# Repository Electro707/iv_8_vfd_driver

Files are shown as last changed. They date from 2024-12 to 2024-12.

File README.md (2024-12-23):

# Dual IV-8 VFD Display Drivers

This project is to drive two IV-8 displays

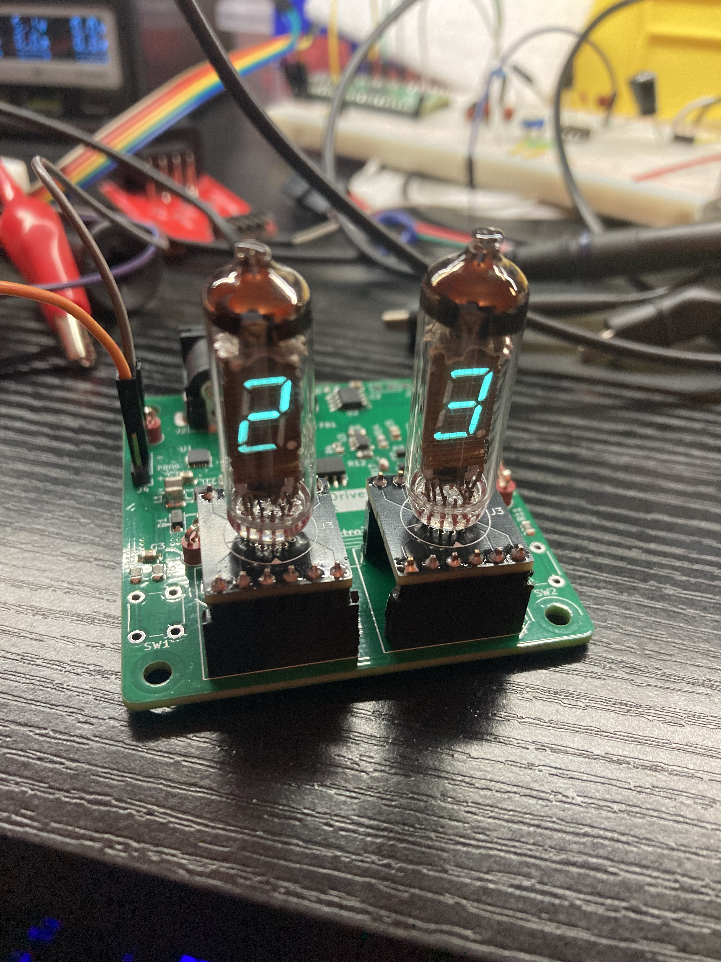
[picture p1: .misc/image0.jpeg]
Image of board, 2024-12-21


# History

This project started because I scored two IV-8 VFD Displays off a flea market, and thus I needed something to drive them

# Project Structure
- CAD: FreeCAD source files for the enclosure (WIP)
- PCB_Driver: KiCAD files for the driver board
- PCB_IV-8: KiCAD files for the IV-8 mounting board
- PCB_IV-8_Test: KiCAD files for a test board equivalent to above, used before using a real display in case the circuit is borked
- Sim_Osci: KiCAD files for a simulation of the oscillating circuit, taken from an EEVBlog forum
- Firmware_count: A simple firmware that counts the VFDs up from 0 to 99
- Firmware_main1: The primary firmware, this one also implements UART communication with a host

# Driver Board Issue, Rev 1
There were some erratas that proped out during testing of Rev 1 of the driver board. The following hardware bug fixes must be made for the board to be usable
- For the filament drive circuit, R17 needs to be shorted, and add two series 25ohm resistor (by cutting traces) of `FIL_A` and `FIL_B`
- Add a series 100kohm resistor between the Q1-Q3 and the outputs of Q6 to the gate of the PFET
    - Turns out there was a maximum Source-to-Gate limit of +-20v, which this circuit clearly exceeds when driving the FETs. With the 100k resistor, when driving the segment Vgs is at -5.83v

# License
This project is licensed under GPLv3. See [LICENSE.md](LICENSE.md) for details.

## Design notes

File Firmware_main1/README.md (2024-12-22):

# Firmware

## Cmake Targets
- `<No Arguments>`: Builds the firmware
- `flash`: Flashes the firmware using jtag2updi, which can be uploaded unto an Arduino board and connected to this board with a 4.7k series resistor
    - See the [jtag2udpi](https://github.com/ElTangas/jtag2updi) project for more details on programming and connections
    - You may have to change the jtag2updi port in CmakeLists.txt

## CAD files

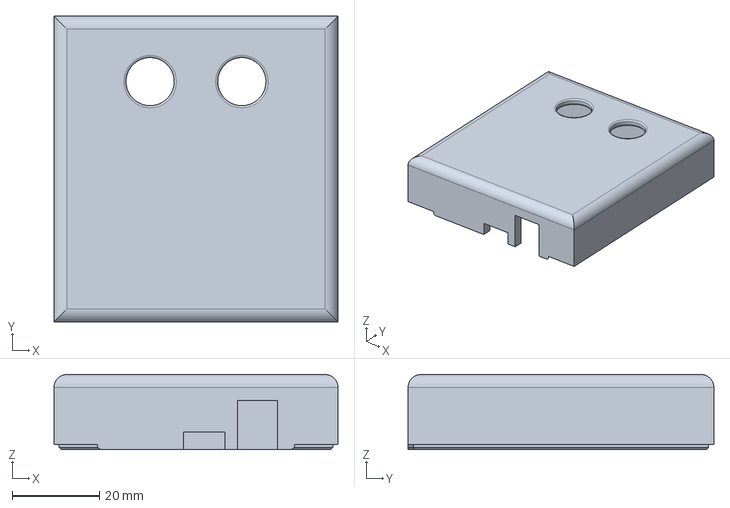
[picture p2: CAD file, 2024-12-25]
CAD/Top.FCStd
65.0 x 70.0 x 17.2 mm

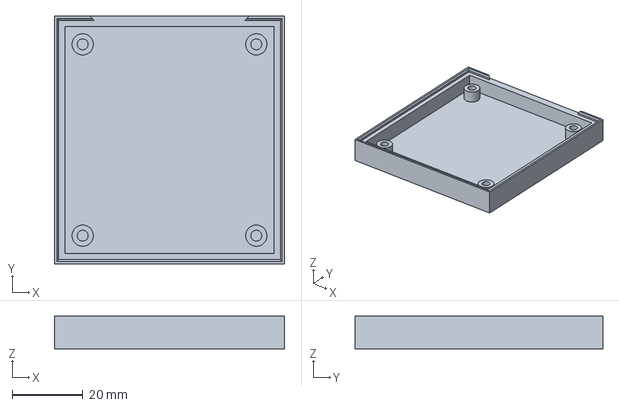
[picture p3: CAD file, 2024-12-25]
CAD/Bottom.FCStd
65.0 x 70.0 x 9.20 mm

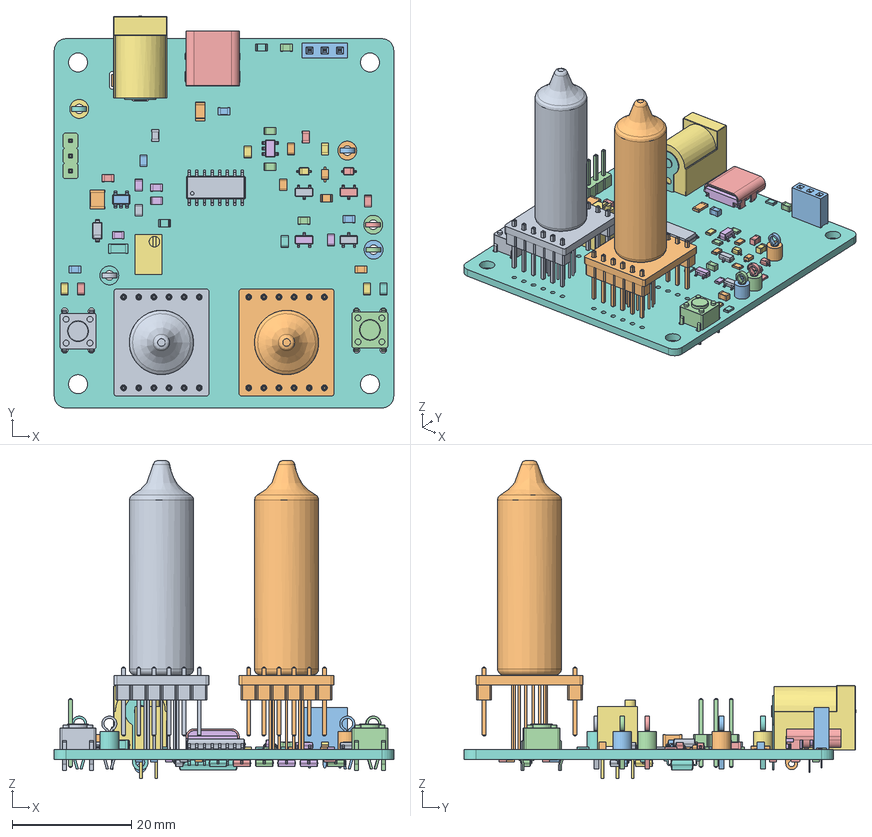
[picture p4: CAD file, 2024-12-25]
CAD/PCB.FCStd
57.0 x 65.8 x 53.4 mm
SOT_23
R_0805_2012Metric
R_0805_2012Metric002
C_0805_2012Metric
SOT_024
R_0805_2012Metric004
L_0805_2012Metric
C_1206_3216Metric
SW_PUSH_6mm
C_0805_2012Metric002
TestPoint_Keystone_5005_5009_Compact_cp
TestPoint_Keystone_5005_5009_Compact_cp001
C_0805_2012Metric004
R_0805_2012Metric006
TestPoint_Keystone_5005_5009_Compact_cp003
TestPoint_Keystone_5005_5009_Compact_cp004
SOIC_16_39x99mm_P127mm
R_0805_2012Metric008
C_0805_2012Metric006
R_0805_2012Metric010
R_0805_2012Metric012
C_0805_2012Metric008
R_0805_2012Metric014
R_0805_2012Metric016
C_0805_2012Metric010
L_1210_3225Metric
L_0805_2012Metric002
C_0805_2012Metric012
USB_C_Receptacle_GCT_USB4085
USB_C_Receptacle_GCT_USB4086
USB_C_Receptacle_GCT_USB4087
USB_C_Receptacle_GCT_USB4088
USB_C_Receptacle_GCT_USB4089
USB_C_Receptacle_GCT_USB4090
USB_C_Receptacle_GCT_USB4091
USB_C_Receptacle_GCT_USB4092
USB_C_Receptacle_GCT_USB4093
USB_C_Receptacle_GCT_USB4094
USB_C_Receptacle_GCT_USB4095
USB_C_Receptacle_GCT_USB4096
USB_C_Receptacle_GCT_USB4097
USB_C_Receptacle_GCT_USB4098
USB_C_Receptacle_GCT_USB4099
USB_C_Receptacle_GCT_USB4100
USB_C_Receptacle_GCT_USB4101
USB_C_Receptacle_GCT_USB4102
USB_C_Receptacle_GCT_USB4103
USB_C_Receptacle_GCT_USB4104
USB_C_Receptacle_GCT_USB4105
USB_C_Receptacle_GCT_USB4106
USB_C_Receptacle_GCT_USB4107
USB_C_Receptacle_GCT_USB4108
USB_C_Receptacle_GCT_USB4109
USB_C_Receptacle_GCT_USB4110
USB_C_Receptacle_GCT_USB4111
USB_C_Receptacle_GCT_USB4112
USB_C_Receptacle_GCT_USB4113
USB_C_Receptacle_GCT_USB4114
USB_C_Receptacle_GCT_USB4115
USB_C_Receptacle_GCT_USB4116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

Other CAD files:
CAD/Assy.FCStd

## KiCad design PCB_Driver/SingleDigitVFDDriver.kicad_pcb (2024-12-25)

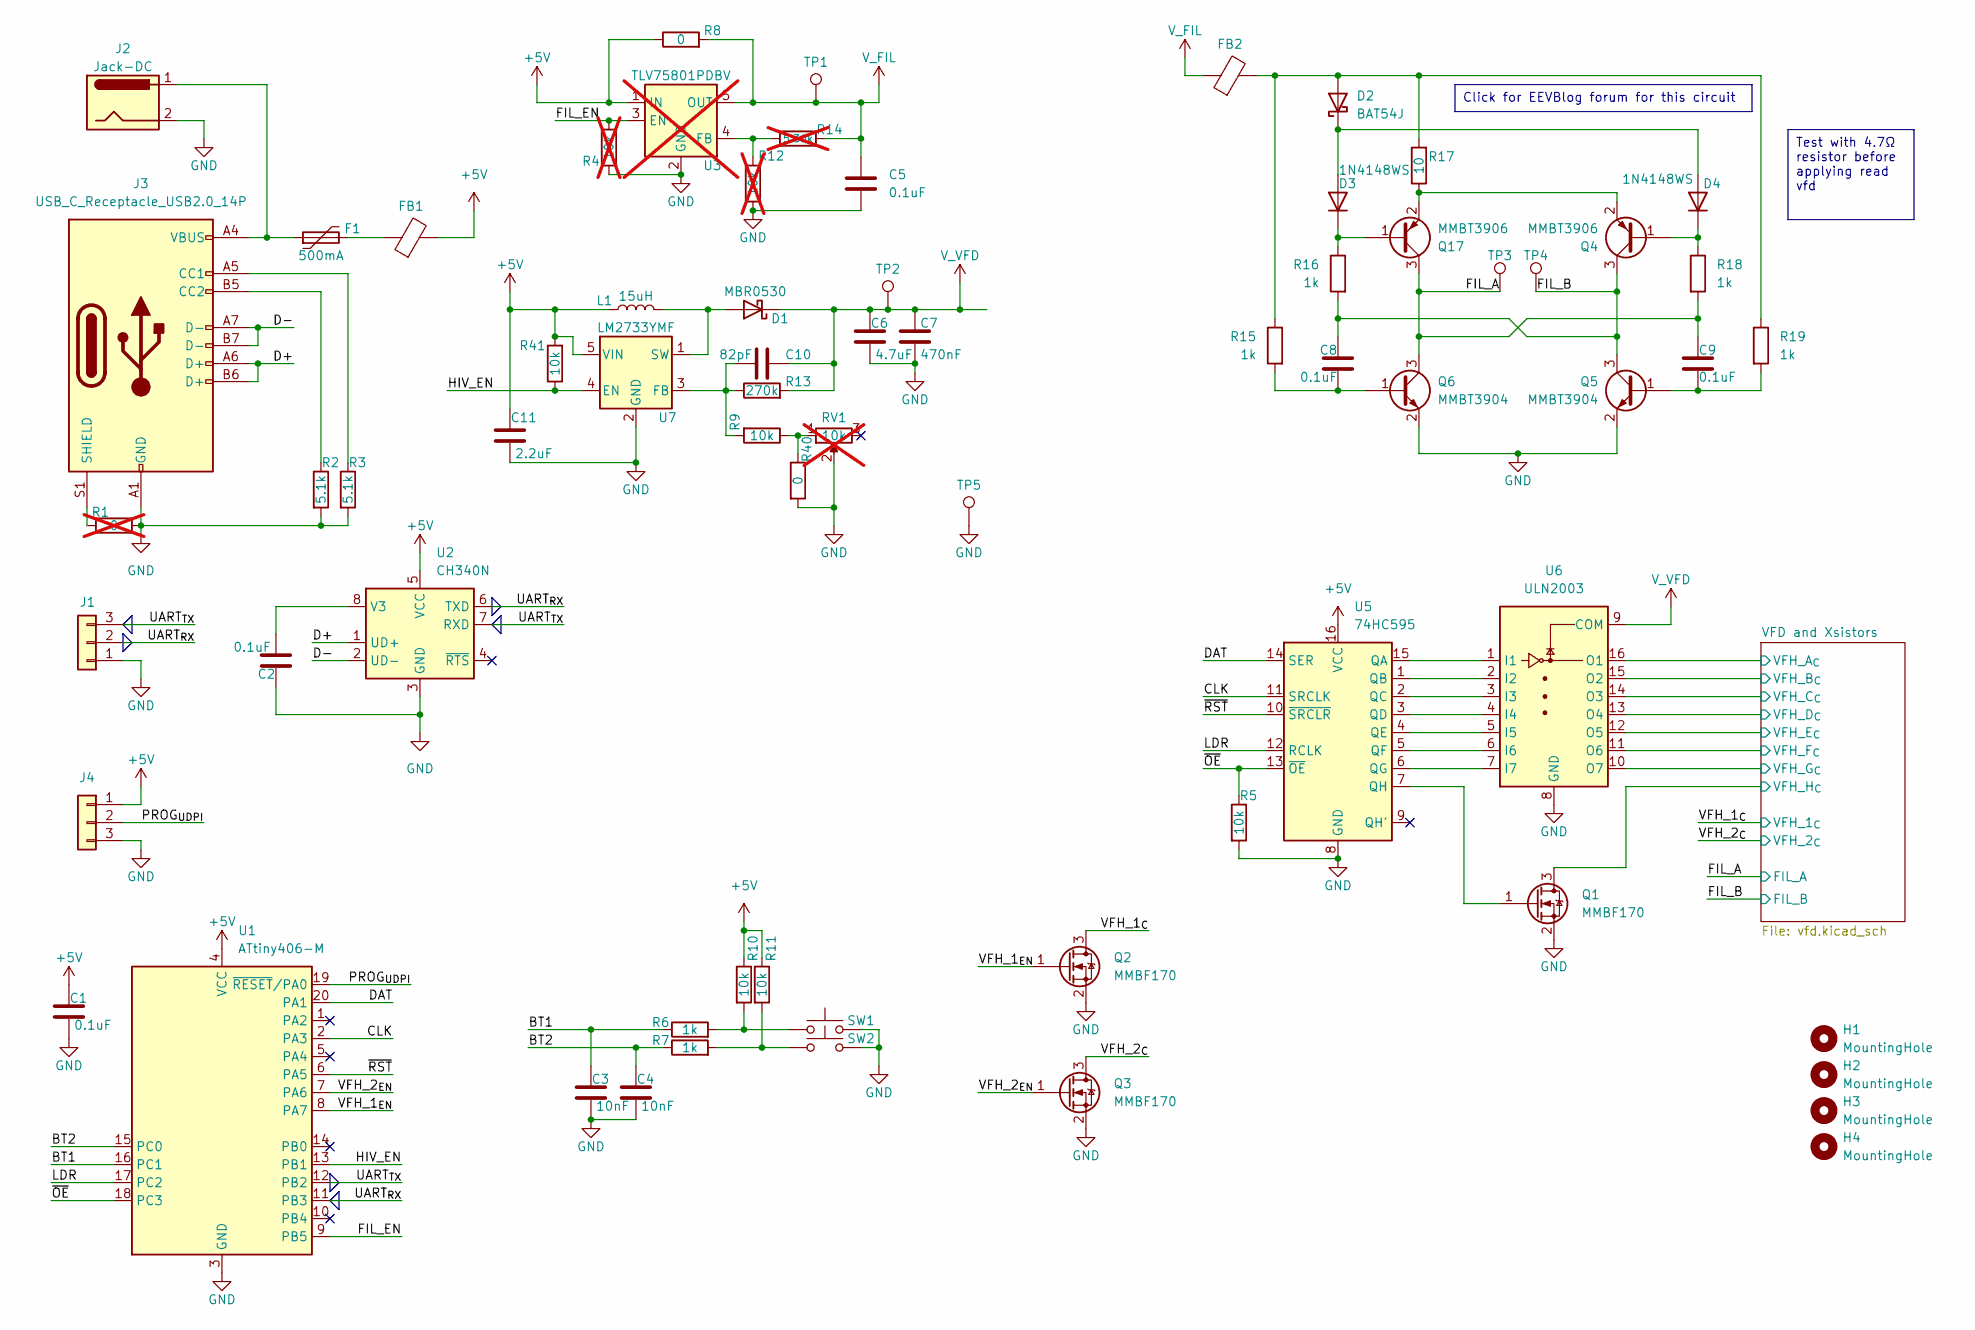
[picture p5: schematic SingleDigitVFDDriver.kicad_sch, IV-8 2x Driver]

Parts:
C1, C2, C5, C8, C9: 0.1uF; C_0805_2012Metric
C3, C4: 10nF; C_0805_2012Metric
C6: 4.7uF; C_1206_3216Metric
C7: 470nF; C_0805_2012Metric
C10: 82pF; C_0805_2012Metric
C11: 2.2uF; C_0805_2012Metric
D1: MBR0530; D_SOD-123
D2: BAT54J; D_SOD-323F
D3, D4: 1N4148WS; D_SOD-323
F1: 500mA; Fuse_1206_3216Metric
FB1, FB2: FerriteBead; L_0805_2012Metric
H1, H2, H3, H4: MountingHole; MountingHole_3.2mm_M3_DIN965
J1: Conn_01x03; PinSocket_1x03_P2.54mm_Vertical
J2: Jack-DC; BarrelJack_Horizontal
J3: USB_C_Receptacle_USB2.0_14P; USB_C_Receptacle_GCT_USB4085
J4: Conn_01x03; PinHeader_1x03_P2.54mm_Vertical
L1: 15uH; L_1210_3225Metric
Q1, Q2, Q3: MMBF170; SOT-23
Q4, Q17: MMBT3906; SOT-23
Q5, Q6: MMBT3904; SOT-23
R1: 0; R_0805_2012Metric; not fitted
R2, R3: 5.1k; R_0805_2012Metric
R4, R12: 10k; R_0805_2012Metric; not fitted
R5, R9, R10, R11, R41: 10k; R_0805_2012Metric
R6, R7, R15, R16, R18, R19: 1k; R_0805_2012Metric
R8, R40: 0; R_0805_2012Metric
R13: 270k; R_0805_2012Metric
R14: 5.36k; R_0805_2012Metric; not fitted
R17: 10; R_0805_2012Metric
RV1: 10k; Potentiometer_Bourns_3266W_Vertical; not fitted
SW1, SW2: SW_Push; SW_PUSH_6mm
TP1, TP2, TP3, TP4, TP5: TestPoint; TestPoint_Keystone_5005-5009_Compact
U1: ATtiny406-M; VQFN-20-1EP_3x3mm_P0.4mm_EP1.7x1.7mm
U2: CH340N; SOP-8_3.9x4.9mm_P1.27mm
U3: TLV75801PDBV; SOT-23-5; not fitted
U5: 74HC595; SOIC-16_3.9x9.9mm_P1.27mm
U6: ULN2003; SOIC-16_3.9x9.9mm_P1.27mm
U7: LM2733YMF; SOT-23-5

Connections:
+5V: C1.1, C11.1, FB1.2, J4.1, L1.1, R8.1, R10.1, R11.1, R41.2, U1.4 (VCC), U2.5 (VCC), U3.1 (IN), U5.16 (VCC), U7.5 (VIN)
/BT1: C3.1, R6.1, U1.16 (PC1)
/BT2: C4.1, R7.1, U1.15 (PC0)
/CLK: U1.2 (PA3), U5.11 (SRCLK)
/D+: J3.A6 (D+), J3.B6 (D+), U2.1 (UD+)
/D-: J3.A7 (D-), J3.B7 (D-), U2.2 (UD-)
/DAT: U1.20 (PA1), U5.14 (SER)
/FIL_A: C9.1, Q6.3 (C), Q17.3 (C), R18.2, TP3.1; also elsewhere on the board
/FIL_B: C8.1, Q4.3 (C), Q5.3 (C), R16.2, TP4.1; also elsewhere on the board
/FIL_EN: R4.2, U1.9 (PB5), U3.3 (EN)
/HIV_EN: R41.1, U1.13 (PB1), U7.4 (EN)
/LDR: U1.17 (PC2), U5.12 (RCLK)
/PROG_{UDPI}: J4.2, U1.19 (~RESET/PA0)
/UART_{RX}: J1.2, U1.11 (PB3), U2.6 (TXD)
/UART_{TX}: J1.3, U1.12 (PB2), U2.7 (RXD)
/VFD and Xsistors/VFH_A_{C}: U6.16 (O1); also elsewhere on the board
/VFD and Xsistors/VFH_B_{C}: U6.15 (O2); also elsewhere on the board
/VFD and Xsistors/VFH_C_{C}: U6.14 (O3); also elsewhere on the board
/VFD and Xsistors/VFH_D_{C}: U6.13 (O4); also elsewhere on the board
/VFD and Xsistors/VFH_E_{C}: U6.12 (O5); also elsewhere on the board
/VFD and Xsistors/VFH_F_{C}: U6.11 (O6); also elsewhere on the board
/VFD and Xsistors/VFH_G_{C}: U6.10 (O7); also elsewhere on the board
/VFD and Xsistors/VFH_H_{C}: Q1.3 (D); also elsewhere on the board
/VFH_1_{C}: Q2.3 (D); also elsewhere on the board
/VFH_1_{EN}: Q2.1 (G), U1.8 (PA7)
/VFH_2_{C}: Q3.3 (D); also elsewhere on the board
/VFH_2_{EN}: Q3.1 (G), U1.7 (PA6)
/~OE: R5.1, U1.18 (PC3), U5.13 (~OE)
/~RST: U1.6 (PA5), U5.10 (~SRCLR)
GND: C1.2, C2.1, C3.2, C4.2, C5.2, C6.2, C7.2, C11.2, J1.1, J2.2, J3.A1 (GND), J3.A12 (GND), J3.B1 (GND), J3.B12 (GND), J4.3, Q1.2 (S), Q2.2 (S), Q3.2 (S), Q5.2 (E), Q6.2 (E), R1.2, R2.2, R3.2, R4.1, R5.2, R12.1, R40.2, RV1.2, SW1.2, SW2.2, TP5.1, U1.3 (GND), U1.21 (GND), U2.3 (GND), U3.2 (GND), U5.8 (GND), U6.8 (GND), U7.2 (GND); also elsewhere on the board
unnamed: D1.2 (A), L1.2, U7.1 (SW)
unnamed: D2.2 (A), FB2.2, R15.1, R17.2, R19.1
unnamed: D2.1 (K), D3.2 (A), D4.2 (A)
unnamed: D3.1 (K), Q17.1 (B), R16.1
unnamed: D4.1 (K), Q4.1 (B), R18.1
unnamed: F1.1, J2.1, J3.A4 (VBUS), J3.A9 (VBUS), J3.B4 (VBUS), J3.B9 (VBUS)
unnamed: F1.2, FB1.1
unnamed: J3.A5 (CC1), R3.1
unnamed: J3.B5 (CC2), R2.1
unnamed: J3.S1 (SHIELD), R1.1
unnamed: Q1.1 (G), U5.7 (QH)
unnamed: C9.2, Q5.1 (B), R19.2
unnamed: C8.2, Q6.1 (B), R15.2
unnamed: Q4.2 (E), Q17.2 (E), R17.1
unnamed: R6.2, R10.2, SW1.1
unnamed: R7.2, R11.2, SW2.1
unnamed: R9.1, R40.1, RV1.1
unnamed: C2.2, U2.8 (V3)
unnamed: R12.2, R14.1, U3.4 (FB)
unnamed: U5.15 (QA), U6.1 (I1)
unnamed: U5.1 (QB), U6.2 (I2)
unnamed: U5.2 (QC), U6.3 (I3)
unnamed: U5.3 (QD), U6.4 (I4)
unnamed: U5.4 (QE), U6.5 (I5)
unnamed: U5.5 (QF), U6.6 (I6)
unnamed: U5.6 (QG), U6.7 (I7)
unnamed: C10.1, R9.2, R13.1, U7.3 (FB)
V_FIL: C5.1, FB2.1, R8.2, R14.2, TP1.1, U3.5 (OUT)
V_VFD: C6.1, C7.1, C10.2, D1.1 (K), R13.2, TP2.1, U6.9 (COM); also elsewhere on the board

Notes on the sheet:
Click for EEVBlog forum for this circuit
Test with 4.7Ω resistor before applying read vfd

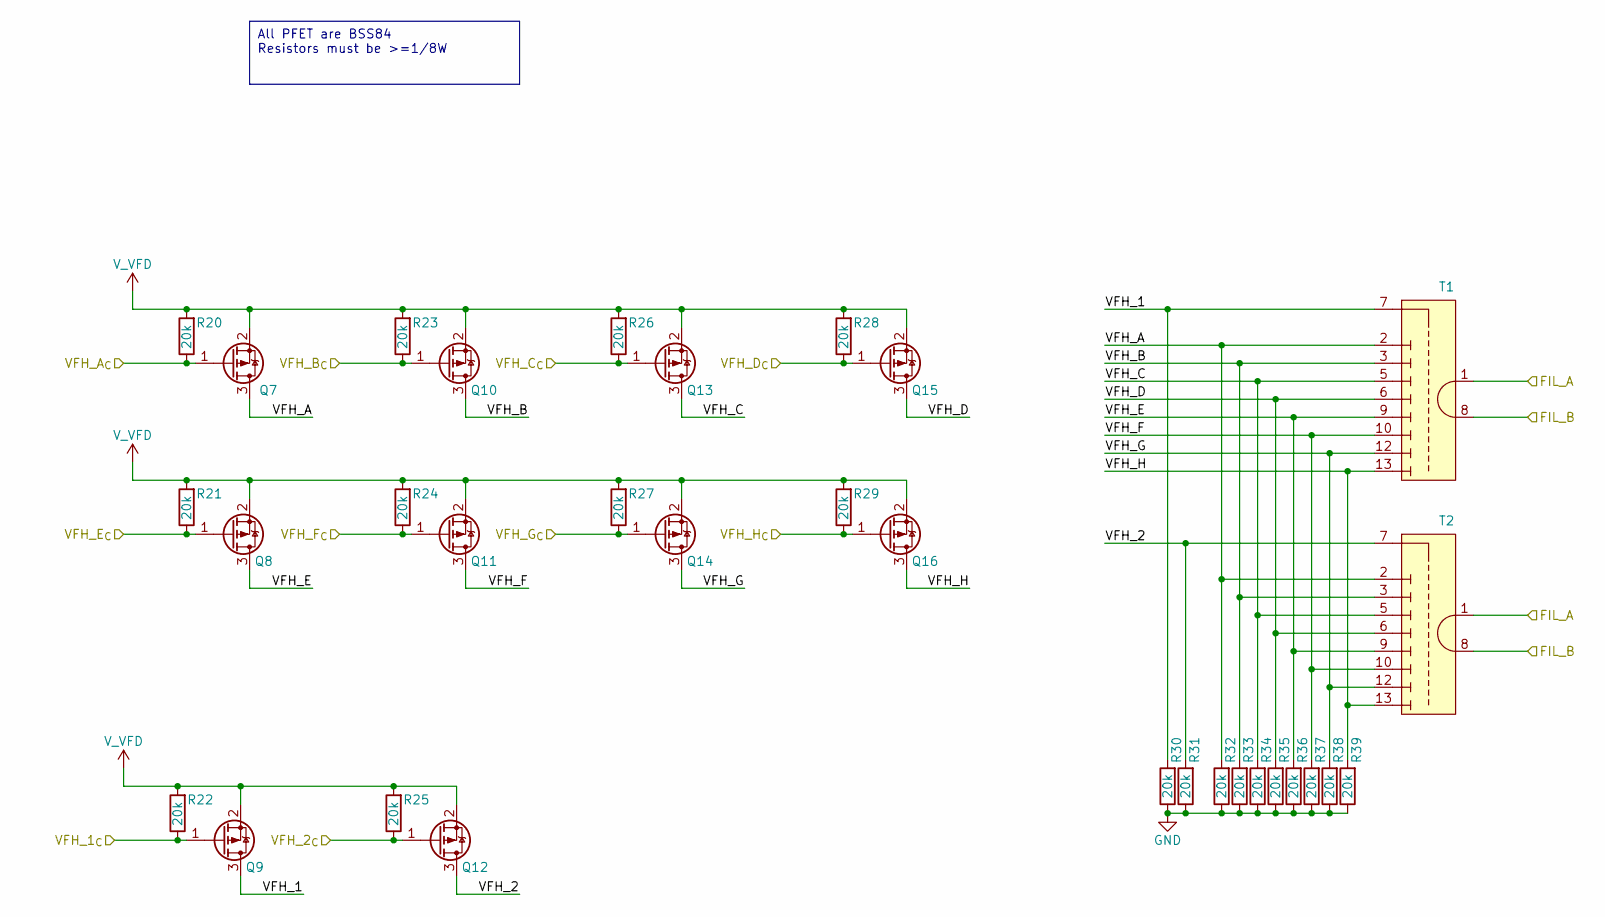
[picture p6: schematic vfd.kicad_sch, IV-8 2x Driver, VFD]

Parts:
Q7, Q8, Q9, Q10, Q11, Q12, Q13, Q14, Q15, Q16: BSS84; SOT-23
R20, R21, R22, R23, R24, R25, R26, R27, R28, R29, R30, R31, R32, R33, R34, R35, R36, R37, R38, R39: 20k; R_0805_2012Metric
T1, T2: IV-8 Adapter

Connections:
/FIL_A: T1.1, T2.1; also elsewhere on the board
/FIL_B: T1.8, T2.8; also elsewhere on the board
/VFD and Xsistors/VFH_1: Q9.3 (D), R30.2, T1.7
/VFD and Xsistors/VFH_2: Q12.3 (D), R31.2, T2.7
/VFD and Xsistors/VFH_A: Q7.3 (D), R32.2, T1.2, T2.2
/VFD and Xsistors/VFH_A_{C}: Q7.1 (G), R20.1; also elsewhere on the board
/VFD and Xsistors/VFH_B: Q10.3 (D), R33.2, T1.3, T2.3
/VFD and Xsistors/VFH_B_{C}: Q10.1 (G), R23.1; also elsewhere on the board
/VFD and Xsistors/VFH_C: Q13.3 (D), R34.2, T1.5, T2.5
/VFD and Xsistors/VFH_C_{C}: Q13.1 (G), R26.1; also elsewhere on the board
/VFD and Xsistors/VFH_D: Q15.3 (D), R35.2, T1.6, T2.6
/VFD and Xsistors/VFH_D_{C}: Q15.1 (G), R28.1; also elsewhere on the board
/VFD and Xsistors/VFH_E: Q8.3 (D), R36.2, T1.9, T2.9
/VFD and Xsistors/VFH_E_{C}: Q8.1 (G), R21.1; also elsewhere on the board
/VFD and Xsistors/VFH_F: Q11.3 (D), R37.2, T1.10, T2.10
/VFD and Xsistors/VFH_F_{C}: Q11.1 (G), R24.1; also elsewhere on the board
/VFD and Xsistors/VFH_G: Q14.3 (D), R38.2, T1.12, T2.12
/VFD and Xsistors/VFH_G_{C}: Q14.1 (G), R27.1; also elsewhere on the board
/VFD and Xsistors/VFH_H: Q16.3 (D), R39.2, T1.13, T2.13
/VFD and Xsistors/VFH_H_{C}: Q16.1 (G), R29.1; also elsewhere on the board
/VFH_1_{C}: Q9.1 (G), R22.1; also elsewhere on the board
/VFH_2_{C}: Q12.1 (G), R25.1; also elsewhere on the board
GND: R30.1, R31.1, R32.1, R33.1, R34.1, R35.1, R36.1, R37.1, R38.1, R39.1; also elsewhere on the board
V_VFD: Q7.2 (S), Q8.2 (S), Q9.2 (S), Q10.2 (S), Q11.2 (S), Q12.2 (S), Q13.2 (S), Q14.2 (S), Q15.2 (S), Q16.2 (S), R20.2, R21.2, R22.2, R23.2, R24.2, R25.2, R26.2, R27.2, R28.2, R29.2; also elsewhere on the board

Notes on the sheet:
All PFET are BSS84 Resistors must be >=1/8W

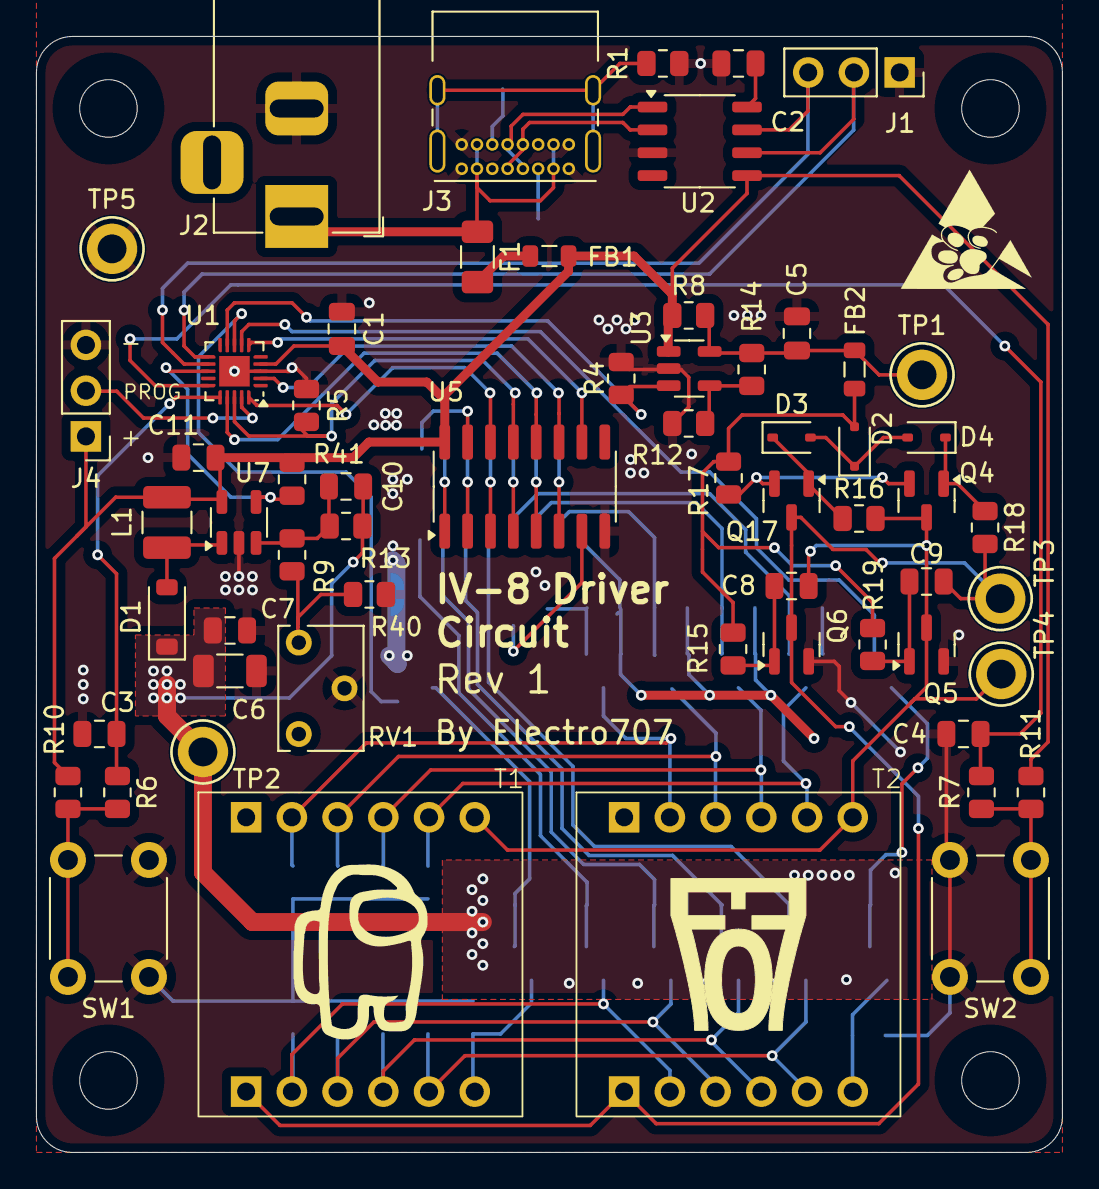
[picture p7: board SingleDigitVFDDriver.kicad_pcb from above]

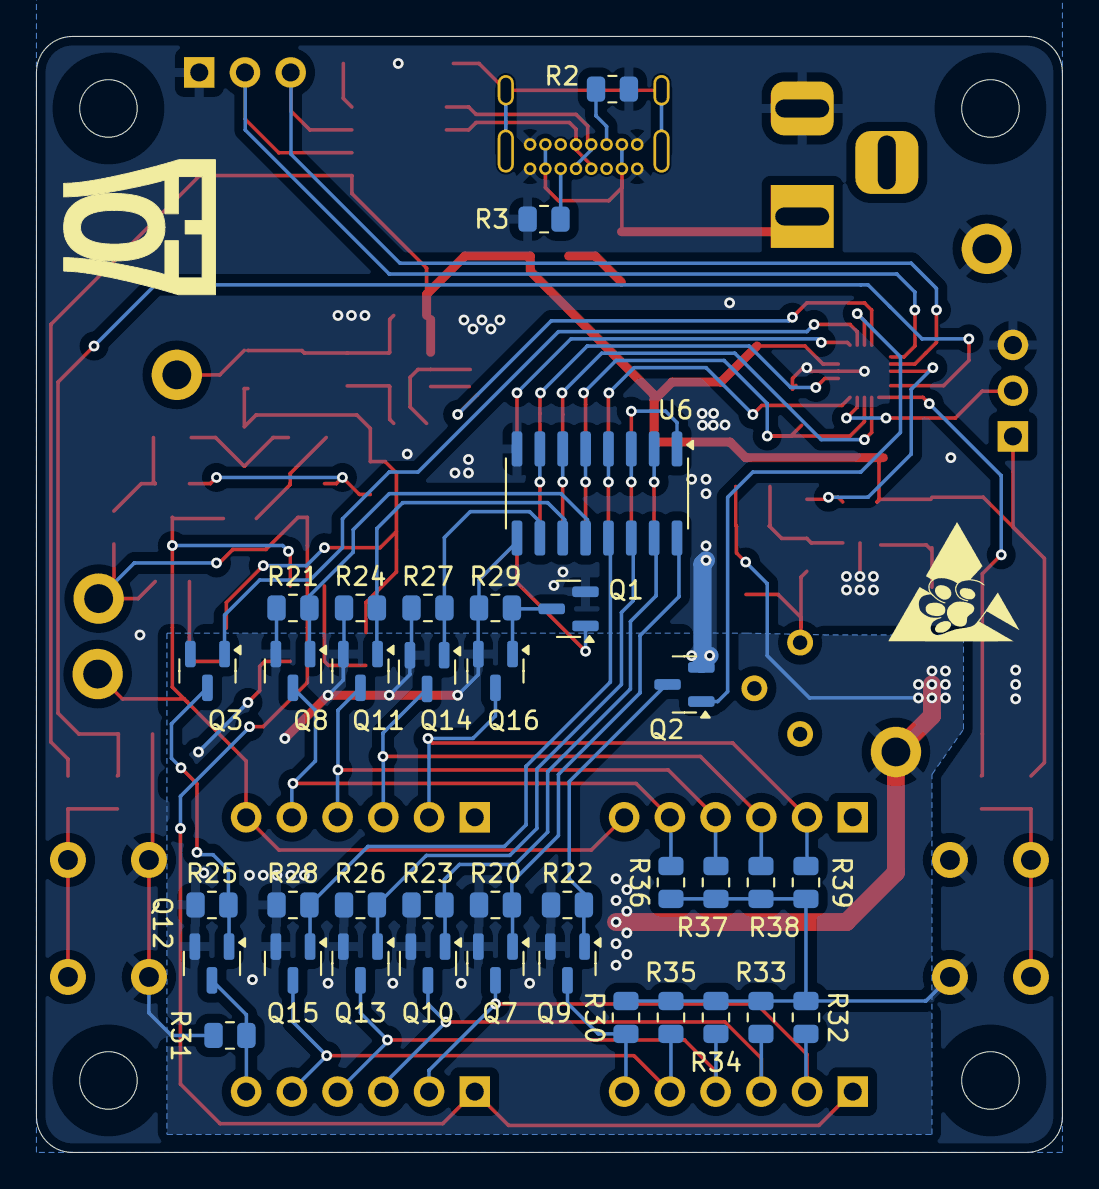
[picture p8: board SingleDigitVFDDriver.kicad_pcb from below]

Board: 2 copper layers, 57.0 x 62.0 mm, 101 parts (36 on the bottom side), 69 nets.

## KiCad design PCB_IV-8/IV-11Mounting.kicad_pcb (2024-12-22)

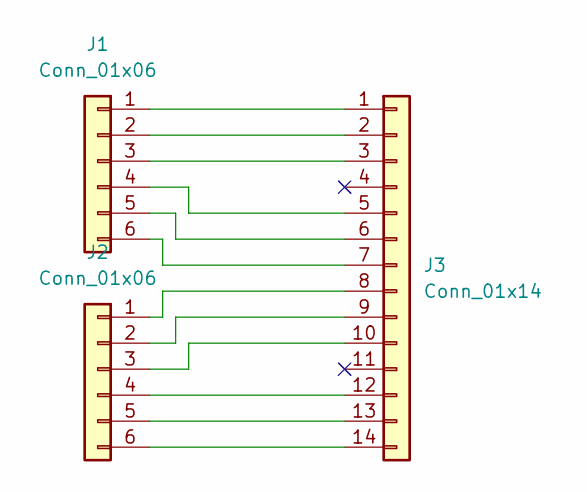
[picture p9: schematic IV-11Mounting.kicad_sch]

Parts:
J1, J2: Conn_01x06; PinHeader_1x06_P2.54mm_Vertical
J3: Conn_01x14; IV-8 VFD

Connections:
unnamed: J1.1, J3.1
unnamed: J1.2, J3.2
unnamed: J1.3, J3.3
unnamed: J1.4, J3.5
unnamed: J1.5, J3.6
unnamed: J1.6, J3.7
unnamed: J2.1, J3.8
unnamed: J2.2, J3.9
unnamed: J2.3, J3.10
unnamed: J2.4, J3.12
unnamed: J2.5, J3.13
unnamed: J2.6, J3.14

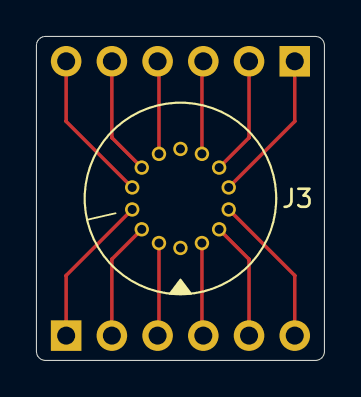
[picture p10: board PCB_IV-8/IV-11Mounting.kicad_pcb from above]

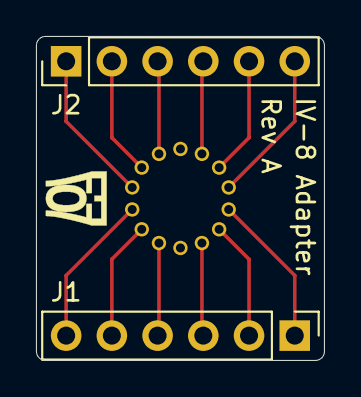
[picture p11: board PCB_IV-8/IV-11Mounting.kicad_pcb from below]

Board: 2 copper layers, 16.0 x 18.0 mm, 3 parts (2 on the bottom side), 12 nets.

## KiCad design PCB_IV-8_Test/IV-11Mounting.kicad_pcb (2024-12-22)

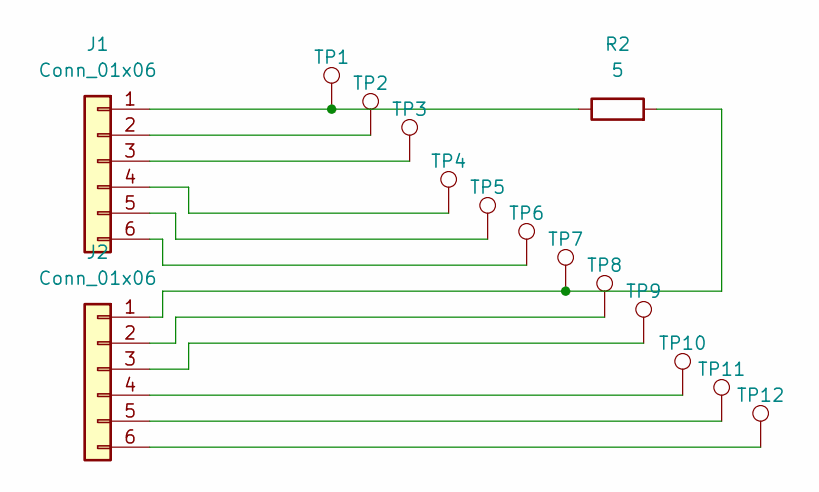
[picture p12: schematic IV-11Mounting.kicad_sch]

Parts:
J1, J2: Conn_01x06; PinHeader_1x06_P2.54mm_Vertical
R2: 5; R_0805_2012Metric_Pad1.20x1.40mm_HandSolder
TP1, TP2, TP3, TP4, TP5, TP6, TP7, TP8, TP9, TP10, TP11, TP12: TestPoint; TestPoint_Pad_1.5x1.5mm

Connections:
unnamed: J1.1, R2.1, TP1.1
unnamed: J1.2, TP2.1
unnamed: J1.3, TP3.1
unnamed: J1.4, TP4.1
unnamed: J1.5, TP5.1
unnamed: J1.6, TP6.1
unnamed: J2.1, R2.2, TP7.1
unnamed: J2.2, TP8.1
unnamed: J2.3, TP9.1
unnamed: J2.4, TP10.1
unnamed: J2.5, TP11.1
unnamed: J2.6, TP12.1

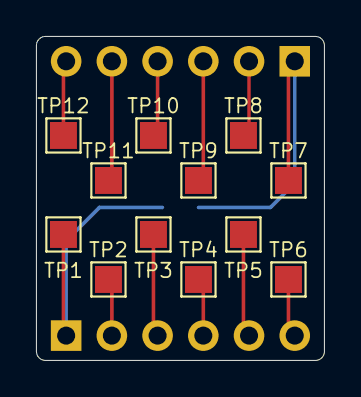
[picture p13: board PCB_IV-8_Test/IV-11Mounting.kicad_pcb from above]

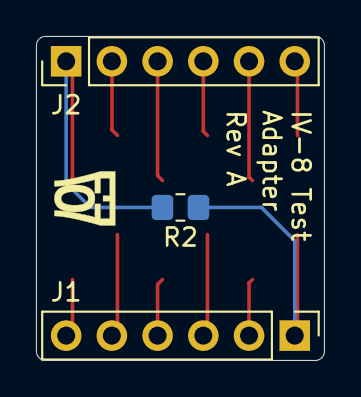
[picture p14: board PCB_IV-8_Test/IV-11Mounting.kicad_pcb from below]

Board: 2 copper layers, 16.0 x 18.0 mm, 15 parts (3 on the bottom side), 12 nets.

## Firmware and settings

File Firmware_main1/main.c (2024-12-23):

/**
 * IV-8 Driver Board Firmware
 * by electro707
 * 
 * Useful notes:
 *     - CPU clock: 16Mhz
 *     - Periferal Clock: 16Mhz
 *     - Real time interrupt: 1Khz
 */
#include <stdbool.h>
#include <stdlib.h>
#include <avr/io.h>
#include <util/delay.h>
#include <avr/interrupt.h>
#include "main.h"
#include "comms.h"

/** Program Configs **/
#define N_SEGMENTS 2

/** Misc Macros **/
#define EVER ;;

/** Pin enable/disable Macros **/
#define PIN_ENA_FILAMENT PORTB_OUTSET = (1 << 5)
#define PIN_DIS_FILAMENT PORTB_OUTCLR = (1 << 5)

#define PIN_ENA_HIV PORTB_OUTSET = (1 << 1)
#define PIN_DIS_HIV PORTB_OUTCLR = (1 << 1)

#define PIN_LDR_RST PORTC_OUTCLR = (1 << 2)
#define PIN_LDR_SET PORTC_OUTSET = (1 << 2)

#define SHIFT_O_ENA     PORTC_OUTCLR = (1 << 3)
#define SHIFT_O_DIS     PORTC_OUTSET = (1 << 3)

#define SHIFT_RESET     PORTA_OUTCLR = (1 << 5)
#define SHIFT_UNRESET   PORTA_OUTSET = (1 << 5)

#define VFD_1_EN        PORTA_OUTSET = (1 << 7)
#define VFD_1_DIS        PORTA_OUTCLR = (1 << 7)

#define VFD_2_EN        PORTA_OUTSET = (1 << 6)
#define VFD_2_DIS        PORTA_OUTCLR = (1 << 6)

// constant to convert an integer into what to be displated
const uint8_t numberToSeg[10] = {0xed, 0x28, 0xce, 0x6e, 0x2b, 0x67, 0xe7, 0x2c, 0xef, 0x6f};
// macros to set or clear the dot in the display
#define SET_DOT(_SEG)   _SEG |= (1 << 5)
#define CLR_DOT(_SEG)   _SEG &= ~(1 << 5)

// a global counter of the current displayed number
uint8_t dispN = 0;

void mcuInit(void){
    CCP = 0xD8;                     // unlock io write for below
    CLKCTRL_MCLKCTRLB = 0x00;       // no divider for periferal clocks

    // init pin output
    SHIFT_O_DIS;        // OE defaults to high, disabled
    SHIFT_RESET;
    VFD_2_DIS;
    VFD_1_DIS;

    // init ports
    PORTA_DIR = 0b11101010;
    PORTB_DIR = 0b00100110;
    PORTC_DIR = 0b1100;

    // init spi for shift register
    SPI0_CTRLB = 0x04;
    SPI0_CTRLA = 0x63;
    SPI0_INTFLAGS = 0;

    // init uart
    USART0_BAUD = 555;
    USART0_CTRLC = 0x03;        // 8 bit, no parity, 1 stop bit
    USART0_CTRLB = 0xc0;        // enable transmitter and receiver
    USART0_CTRLA = 0x80;
    
    // set the shift register output to 0 (nothing is enabled)
    SHIFT_UNRESET;
    PIN_LDR_RST;
    SPI0_DATA = 0;
    while((SPI0_INTFLAGS & (1 << 7)) == 0);
    PIN_LDR_SET;

    // init real time clock, 1Khz
    TCB0_CTRLB = 0x00;
    TCB0_INTCTRL = 1;
    TCB0_CCMP = 16000UL;
    TCB0_CTRLA = 0x01;      // enable clock, no divider
}

int main(void){
    mcuInit();

    // PIN_ENA_FILAMENT;    // not needed
    PIN_ENA_HIV;

    sei();

    for(EVER){
        // everything is handled in interrupt
        processUart();
    }

    return 0;
}

ISR(TCB0_INT_vect){
    static uint8_t swapDispCnt = 0;         // counter to swap the shown display
    static uint8_t currDisp = 0;               // the current shown display
    static uint16_t incSegCnt = 0;             // counter to increment the displayed number

    uint8_t toShowN;                        // current number to be shown on the current segment

    TCB0_INTFLAGS = 1;

    if(swapDispCnt++ >= 2){
        SHIFT_O_DIS;
        VFD_1_DIS;
        VFD_2_DIS;

        swapDispCnt = 0;

        currDisp++;
        currDisp &= 1;

        if(currDisp == 0){
            toShowN = dispN % 10;
        } else {
            toShowN = dispN / 10;
        }

        PIN_LDR_RST;
        // SPI0_INTFLAGS = 0;
        SPI0_DATA = numberToSeg[toShowN];
        while((SPI0_INTFLAGS & (1 << 7)) == 0);
        PIN_LDR_SET;
        
        if(currDisp == 0){
            VFD_1_DIS;
            VFD_2_EN;
        } else {
            VFD_1_EN;
            VFD_2_DIS;
        }
        SHIFT_O_ENA;
    }

    // if(incSegCnt++ >= 250){      // increment number every 250mS
        // incSegCnt = 0;
        // dispN++;
        // if(dispN == 100){
        //     dispN = 0;
        // }
        // USART0_TXDATAL = (dispN%10) + '0';
    // }
}

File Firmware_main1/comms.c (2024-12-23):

/**
 * Communication Handler
 * by electro707
 * 
 * This files handles communication functions over UART to/from the PC
 * 
 */

#include <string.h>
#include <avr/io.h>
#include <avr/interrupt.h>
#include "comms.h"
#include "main.h"

const char helpTxt[] = \
    "Commands:\n" \
    "\tping: pong!\n" \
    "\td X: Set the display number to X\n" \
    "\0";

uint8_t rxBuff[FIFO_SIZE];
fifo_t rxFifo = {
    .buff = rxBuff,
    .in = 0,
    .out = 0,
};

uint8_t txBuff[FIFO_SIZE];
fifo_t txFifo = {
    .buff = txBuff,
    .in = 0,
    .out = 0,
};

uint8_t resv_nl = 0;        // flag when we receive new line

void uartTxString(const char *toSend);
int fifoGet(fifo_t *f, uint8_t *out);

// this function gets called when the application has time to process and UART commands
// low priority
void processUart(void){
    if(resv_nl == 0){
        return;
    }
    resv_nl = 0;

    // if we finally got a line, process it
    // while we can do a binary search tree, for now read entire buffer then process on it with strcmp
    char readTxt[32];
    uint8_t readTxtIdx = 0;
    uint8_t stat;
    char *token;

    while(1){
        stat = fifoGet(&rxFifo, (uint8_t *)(readTxt + readTxtIdx));
        if(stat != 0){
            break;
        }
        if(readTxt[readTxtIdx] == '\n'){
            readTxt[readTxtIdx] = 0;
            break;
        }
        // todo: handle '\r' characters
        if(++readTxtIdx >= 32){
            readTxt[readTxtIdx-1] = 0;
            break;
        }
    }

    token = strtok(readTxt, " ");

    if(!strcmp(token, "help")){
        uartTxString(helpTxt);
    }
    else if(!strcmp(token, "ping")){
        uartTxString("pong!\n");
    }
    else if(!strcmp(token, "d")){
        token = strtok(NULL, " ");
        stat = atoi(token);
        if(stat >= 100){
            stat = 99;
        }
        dispN = stat;
    }
    else{
        uartTxString("invalid\n");
    }
}

void uartTxString(const char *toSend){
    // for now no FIFO, just send direct
    while(*toSend){
        USART0_TXDATAL = *toSend++;
        while((USART0_STATUS & (1 << 5)) == 0);
    }
    
}

int fifoGet(fifo_t *f, uint8_t *out){
    // if we are at the same pointer as IN, that means we don't have any more data to read
    if(f->in == f->out){
        *out = 0;
        return -1;
    }

    *out = f->buff[f->out];

    f->out++;
    f->out &= FIFO_MSK;

    return 0;
}

int fifoPut(fifo_t *f, uint8_t in){
    // if the next write will wrap over to OUT (i.e we didn't read the data), don't and return error
    if(((f->out - 1) & FIFO_MSK) == f->in){
        return -1;
    }

    f->buff[f->in] = in;

    f->in++;
    f->in &= FIFO_MSK;

    return 0;
}

ISR(USART0_RXC_vect){
    // todo: read what we received
    char c = USART0_RXDATAL;

    fifoPut(&rxFifo, c);

    if(c == '\n'){
        resv_nl = 1;
    }
    
}

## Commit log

2024-12-23 Started work on enclosure. Created new firmware that isn't just a counter:
    [Assy.FCStd, Bottom.FCStd, PCB.FCStd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]
2024-12-25 Added top enclosure
    [Assy.FCStd, Bottom.FCStd, PCB.FCStd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]
